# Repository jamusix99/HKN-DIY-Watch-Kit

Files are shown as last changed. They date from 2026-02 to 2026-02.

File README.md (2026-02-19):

# HKN Beta Psi DIY Watch Project
By: John Mentgen \
Init Date: 2026-02-16

## Directory Setup
 - **HW Design**: KiCad files for board setup
 - **SW**: Software Repo with details on how to compile

## Project Purpose
This project is meant to provide new ECEN students with a fun soldering project that members of IEEE and HKN Beta-Psi can help with and talk to students about possibilities in this field. The file holding the BOM details rough cost estimates for buying new parts from DigiKey and boards from JLCPCB.

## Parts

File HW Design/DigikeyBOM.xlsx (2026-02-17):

Digi-Key: Shopping Cart
Index | Quantity | Part Number | Manufacturer Part Number | Description | Customer Reference | Available | Backorder | Unit Price | Extended Price USD
1 | 1 | TDCR1050M-ND | TDCR1050M | DISP 7SEG 0.39" QUAD RED 16DIP |  | 1 | 0 | 3.48 | 3.48
2 | 1 | ATTINY85-20PU-ND | ATTINY85-20PU | IC MCU 8BIT 8KB FLASH 8DIP |  | 1 | 0 | 1.66 | 1.66
3 | 2 | 296-33695-5-ND | SN74AHCT595N | IC SR TRI-STATE 8BIT 16-PDIP |  | 2 | 0 | 0.9 | 1.80
4 | 1 | BH800S-ND | BH800S | BATT HLD COIN 20MM 2 CELL PC PIN |  | 1 | 0 | 1.35 | 1.35
5 | 2 | 5210-CR2032-ND | CR2032 | CR2032 20.0mn 3V Coin Cell |  | 2 | 0 | 0.58 | 1.16
6 | 1 | 478-TAP334K050CCS-ND | TAP334K050CCS | CAP TANT 0.33UF 10% 50V RADIAL |  | 1 | 0 | 0.6 | 0.60
7 | 4 | BC1084CT-ND | K104K15X7RF5TL2 | CAP CER 0.1UF 50V X7R RADIAL |  | 4 | 0 | 0.26 | 1.04
8 | 9 | CF18JT1K00CT-ND | CF18JT1K00 | RES 1K OHM 5% 1/8W AXIAL |  | 9 | 0 | 0.1 | 0.90
9 | 1 | SW402-ND | B3F-1020 | SWITCH TACTILE SPST-NO 0.05A 24V |  | 1 | 0 | 0.25 | 0.25
 |  |  |  |  |  |  | Price per kit: | 12.24
 |  |  |  |  |  |  | JLC Run (5x): | 25.75 | (+shipping)
 |  |  |  |  |  |  | JLC Run (25x): | 33.75 | (+shipping)
 |  |  |  |  |  |  | Proto run (x5): | 86.95
 |  |  |  |  |  |  | Prod run (x25): | 339.75

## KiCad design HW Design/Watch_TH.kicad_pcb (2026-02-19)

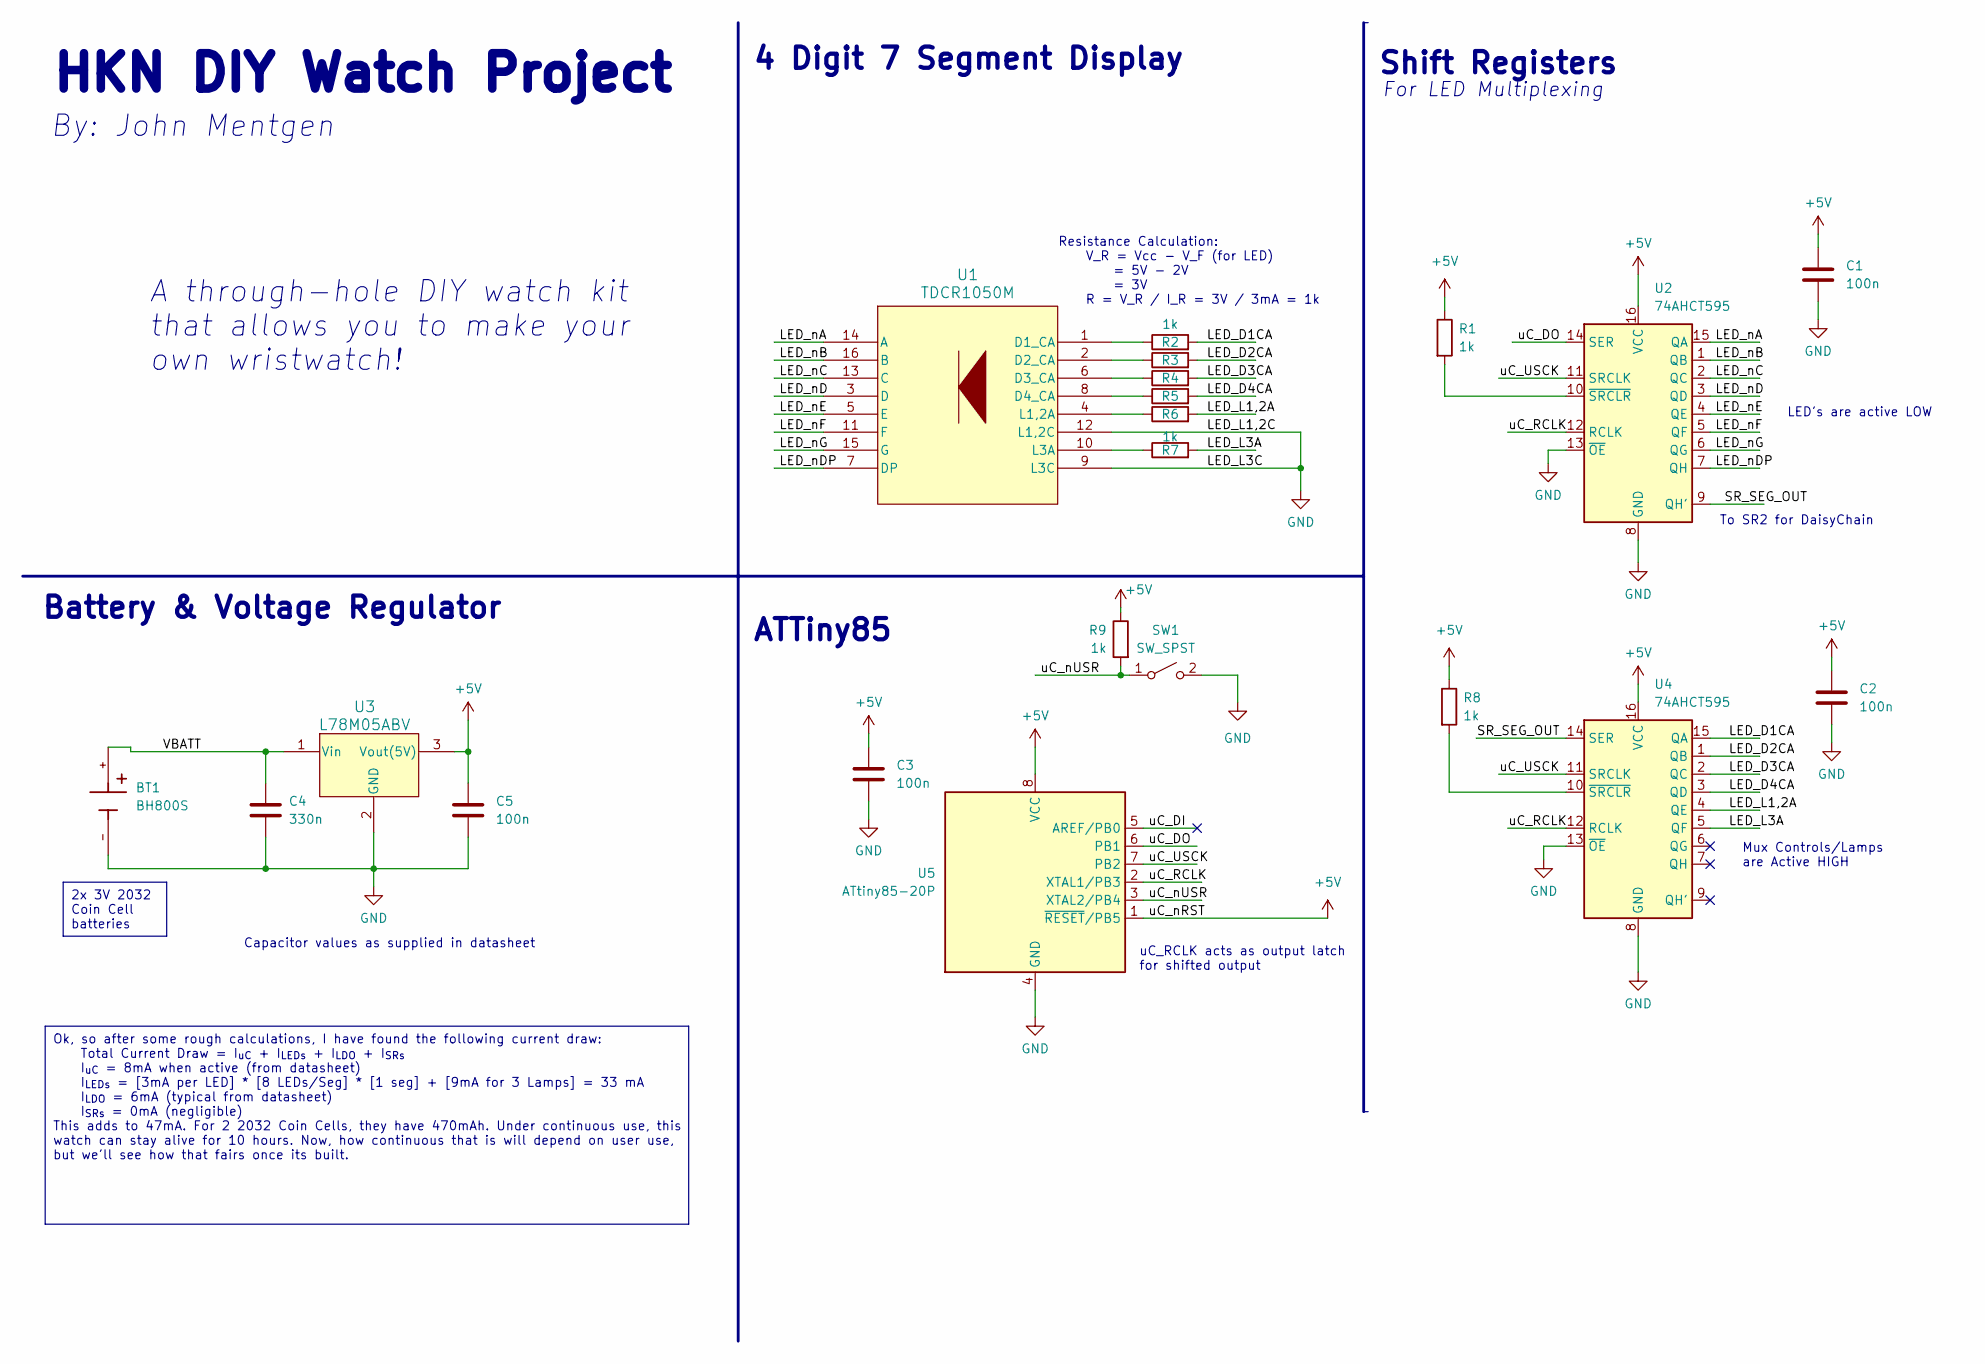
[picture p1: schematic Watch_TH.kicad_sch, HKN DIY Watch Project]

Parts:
BT1: BH800S; BAT_BH800S; PARTREV F
C1, C2, C3, C5: 100n; C_Rect_L4.0mm_W2.5mm_P2.50mm
C4: 330n; C_Radial_D6.3mm_H7.0mm_P2.50mm
R1, R2, R3, R4, R5, R6, R7, R8, R9: 1k; R_Axial_DIN0207_L6.3mm_D2.5mm_P10.16mm_Horizontal
SW1: SW_SPST; SW_PUSH_6mm
U1: TDCR1050M; TDCG1060M_VIS
U2, U4: 74AHCT595; DIP-16_W7.62mm
U3: L78M05ABV; TO-220_STM
U5: ATtiny85-20P; DIP-8_W7.62mm

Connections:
+5V: C1.1, C2.1, C3.1, C5.1, R1.1, R8.1, R9.1, U2.16 (VCC), U3.3 (Vout(5V)), U4.16 (VCC), U5.1 (~RESET/PB5), U5.8 (VCC)
/LED_D1CA: R2.2, U4.15 (QA)
/LED_D2CA: R3.2, U4.1 (QB)
/LED_D3CA: R4.2, U4.2 (QC)
/LED_D4CA: R5.2, U4.3 (QD)
/LED_L1,2A: R6.2, U4.4 (QE)
/LED_L3A: R7.2, U4.5 (QF)
/LED_nA: U1.14 (A), U2.15 (QA)
/LED_nB: U1.16 (B), U2.1 (QB)
/LED_nC: U1.13 (C), U2.2 (QC)
/LED_nD: U1.3 (D), U2.3 (QD)
/LED_nDP: U1.7 (DP), U2.7 (QH)
/LED_nE: U1.5 (E), U2.4 (QE)
/LED_nF: U1.11 (F), U2.5 (QF)
/LED_nG: U1.15 (G), U2.6 (QG)
/SR_SEG_OUT: U2.9 (QH'), U4.14 (SER)
/VBATT: BT1.+, C4.1, U3.1 (Vin)
/uC_DI: U5.5 (AREF/PB0)
/uC_DO: U2.14 (SER), U5.6 (PB1)
/uC_RCLK: U2.12 (RCLK), U4.12 (RCLK), U5.2 (XTAL1/PB3)
/uC_USCK: U2.11 (SRCLK), U4.11 (SRCLK), U5.7 (PB2)
/uC_nUSR: R9.2, SW1.1 (A), U5.3 (XTAL2/PB4)
GND: BT1.-, C1.2, C2.2, C3.2, C4.2, C5.2, SW1.2 (B), U1.9 (L3C), U1.12 (L1,2C), U2.8 (GND), U2.13 (~OE), U3.2 (GND), U4.8 (GND), U4.13 (~OE), U5.4 (GND)
unnamed: R2.1, U1.1 (D1_CA)
unnamed: R3.1, U1.2 (D2_CA)
unnamed: R4.1, U1.6 (D3_CA)
unnamed: R5.1, U1.8 (D4_CA)
unnamed: R6.1, U1.4 (L1,2A)
unnamed: R7.1, U1.10 (L3A)
unnamed: R1.2, U2.10 (~SRCLR)
unnamed: R8.2, U4.10 (~SRCLR)

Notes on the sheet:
Ok, so after some rough calculations, I have found the following current draw: Total Current Draw = I_{uC} + I_{LEDs} + I_{LDO} + I_{SRs} I_{uC} = 8mA when active (from datasheet) I_{LEDs} = [3mA per LED] * [8 LEDs/Seg] * [1 seg] + [9mA for 3 Lamps] = 33 mA I_{LDO} = 6mA (typical from datasheet) I_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
2x 3V 2032 Coin Cell batteries
uC_RCLK acts as output latch for shifted output
Battery & Voltage Regulator
Shift Registers
LED's are active LOW
For LED Multiplexing
A through-hole DIY watch kit that allows you to make your own wristwatch!
Mux Controls/Lamps are Active HIGH
Resistance Calculation: V_R = Vcc - V_F (for LED) = 5V - 2V = 3V R = V_R / I_R = 3V / 3mA = 1k
To SR2 for DaisyChain
HKN DIY Watch Project
By: John Mentgen
ATTiny85
4 Digit 7 Segment Display
Capacitor values as supplied in datasheet

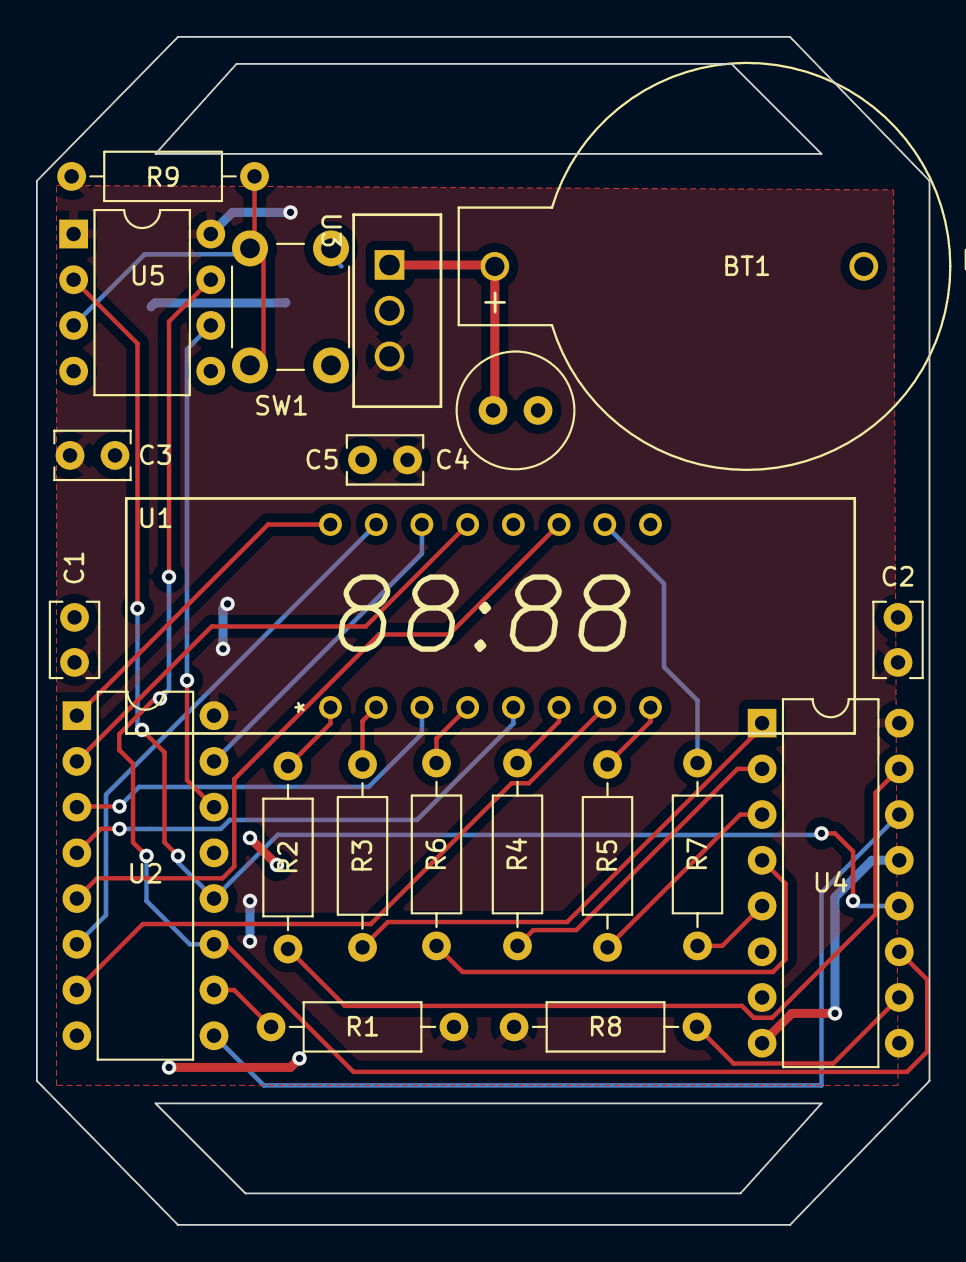
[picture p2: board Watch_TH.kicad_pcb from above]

Board: 2 copper layers, 49.6 x 66.0 mm, 21 parts (0 on the bottom side), 30 nets.
